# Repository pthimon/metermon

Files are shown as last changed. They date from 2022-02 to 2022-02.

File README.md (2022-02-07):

# Battery-Powered Utility Meter Usage Monitor

Do you have a "dumb" utility meter that you want to be able to track your usage
without replacing it? And do you want to run it from a battery? Then this
project is for you! (If you do have a power socket nearby then other projects e.g.
[Home Assistant Glow](https://github.com/klaasnicolaas/home-assistant-glow) are
more appropriate)

## Prerequisites

Your utility meter must either have an LED that pulses for each unit consumed,
or have a magnet in the dial that can be tracked with a reed switch.

IMAGE ELECTRICITY METER
IMAGE GAS METER

If your utility meter has 2 rates (e.g. Economy 7 electricity meter) then make
2 of the photodiode boards and use the `meter_2_rates` project, otherwise use
the `meter_1_rate` project.

You will also need an MQTT broker installed and (optionally) a Home Assistant
server.

## Hardware

- Low-power-capable ESP32 ([FireBeetle ESP32-E IoT Microcontroller](https://thepihut.com/products/firebeetle-esp32-e-iot-microcontroller-supports-wi-fi-bluetooth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))
- Dupont jumpers
- Photodiode or reed switch (depending on your meter type)
- 1 MOhm resistor (brown black green)
- [Vero/strip board](https://www.amazon.co.uk/gp/product/B08D2HP4B3/ref=ppx_yo_dt_b_asin_title_o06_s00?ie=UTF8&psc=1)
- [LiPo battery](https://www.amazon.co.uk/gp/product/B08214DJLJ/ref=ppx_yo_dt_b_asin_title_o00_s00?ie=UTF8&psc=1)
(1,000 - 2,000 mAh capacity should be plenty)
- USB C cable
- Blu Tack / electrical tape
- (Optional) Male header pins (if your ESP comes with soldered headers, you'll need 3 more pins)
- (Optional) USB power bank

## Tools

- Soldering iron
- Sharp knife (to cut low power trace)
- Side cutters (to trim resistor/photosensor leads)
- Tiny screwdriver (to fix battery connector)
- (Optional) 3D Printer
- (Optional) Breadboard (to help solder header pins)
- (Optional) Multi-meter (to assist positioning reed switch)

# Preparing Hardware

If your FireBeetle comes without headers pins, then solder them on. If you do not
have additional header pins, then break off a set of three pins before soldering,
making sure that the missing pins are furthest away from the USB port.

The easiest way to solder is to use a breadboard to hold the pins in place
while they are soldered.

Cut the "Low power" trace with a sharp knife. After doing this I measured the
deep sleep current to be about 14 uA.

[IMAGE TRACE]

## Sensors

The photodiode or reed switch can be connected to pin A3 (for the first sensor)
or pint A1 (if connecting a second sensor):

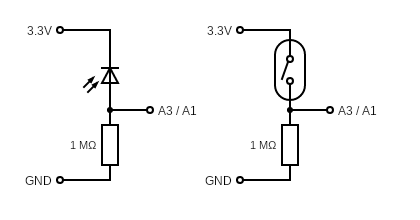
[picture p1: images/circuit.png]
Circuit


Cut the veroboard into a 3x3 square (11x11mm) with a sharp knife or old side cutters.

Solder the 3 header pins, the resistor and either the photodiode or the reed
switch to the board.

The photodiode should have its flat edge against the 3.3V pin.

Ensure the photodiode is on the opposite side of the board to the
header pins so that it can be positioned flush against the LED on the meter, or
that the reed switch has enough slack in the connecting wires to be easily
positioned in the correct place on the meter.

[IMAGE PHOTODIODE]

[IMAGE REEDSWITCH]

# Installing Software

Follow the [quickstart for ESP-IDF](https://docs.espressif.com/projects/esp-idf/en/latest/esp32/get-started/index.html)
to install the SDK and any dependencies.
Install [usb serial drivers](https://wiki.dfrobot.com/FireBeetle_Board_ESP32_E_SKU_DFR0654#target_11) (if necessary)

`. $HOME/esp/esp-idf/export.sh` (or where you installed the esp-idf SDK)

Clone this repository

`cd meter_1_rate` (if using one photodiode/reed switch)<br>
or<br>
`cd meter_2_rates` (if using 2 photodiodes)

`idf.py menuconfig`

Select "Meter Configuration":

- Enter the meter name, which is used as the MQTT topic prefix, e.g. `electricity` or `gas`
- WiFi network name (ssid)
- WiFi password
- MQTT broker URL
- Use Static IP: Un-checked
- Use Button debug: Checked

Connect the FireBeetle to the USB port of the computer.

```bash
idf.py build
idf.py -p /dev/cu.wchusbserial1410 flash # (replace the port with the correct one for your device)
idf.py monitor
```

## Set static IP

Press the button marked with `27` (*not* the `RST` button) on the FireBeetle. The
green LED will flash, and log entries will appear in the console. Find out the IP address
assigned by looking for the log line starting `got ip:`, and configure your
router so that the device is given a static IP address. This will save a lot of
battery life by speeding up the WiFi connect process.

`idf.py menuconfig`

Select "Meter Configuration":

- Use Static IP: Checked
- Static IP address
- Gateway IP (IP address of your router)
- Netmask

```bash
idf.py build
idf.py -p /dev/cu.wchusbserial1410 flash # (replace the port with the correct one for your device)
idf.py monitor
```

## Test

Using a program such as MQTT Explorer, you can verify that the pulse count is
being correctly published to `{meter_name}/total`, and the battery voltage to
`{meter_name}/battery`. (Ensure you are connected before pressing the button).

If the count isn't received by MQTT, the debug level can be increased to show more
information during the WiFi and MQTT connect process by changing the menuconfig:
"Component Config" > "Log Output" > "Default Log Verbosity": "Verbose"

## Install

Install the final version of the software.

`idf.py menuconfig`

Select "Meter Configuration":

- Use Button debug: Un-checked

```bash
idf.py build
idf.py -p /dev/cu.wchusbserial1410 flash # (replace the port with the correct one for your device)
```

## Battery

Before connecting the battery **double check the polarity of the connector**.
If the red wire does not line up with the `+` symbol on the board, then use a
tiny screwdriver to lift the tab to swap over the wires in the connector.

Connect the battery to the FireBeetle to charge it while connected via USB to
the computer. The red light will be solid while charging, and will flash
rapidly once charged. It should reach about 4.2V when fully charged. The
battery should have protection to not discharge below 2.5 V, but to play it
safe, this project is setup to report 0% battery and go into deep sleep when the
voltage is below 3 V.

[IMAGE battery]

## Home Assistant

Edit your Home Assistant `configuration.yaml` to setup MQTT sensors to receive the
meter values and battery voltage and percentage.

Replace ``"electricity"`` in the `state_topic` with the name you configured your
MQTT topic prefix to be.

If necessary, replace `0.001` in the line containing
`value_template: "{{ value | float * 0.001 }}"`
based on how many impulses make a unit, as stated on the meter (e.g.
`1 imp = 0.001kWh`).

```yaml
sensor:
  - platform: mqtt
    name: Electricity Meter
    unique_id: electricity_meter
    state_class: total_increasing
    device_class: energy
    state_topic: "electricity/total"
    unit_of_measurement: kWh
    value_template: "{{ value | float * 0.001 }}"
  - platform: mqtt
    name: Electricity Meter Battery Voltage
    unique_id: electricity_meter_battery_voltage
    device_class: voltage
    state_topic: "electricity/battery"
    unit_of_measurement: V
    value_template: "{{ value | float }}"
  - platform: mqtt
    name: Electricity Meter Battery
    unique_id: electricity_meter_battery
    device_class: battery
    unit_of_measurement: "%"
    state_topic: "electricity/battery"
    value_template: "{{ (([(value|float - 3), 1.2]|min / 1.2) * 100) | round(1) }}"
```

Restart Home Assistant for this to take effect.

# Case

3D Print the following files, depending on your setup:

- Case body
- Case insert (to separate the battery and the FireBeetle)
- Case lid for 1 sensor or Case lid for 2 sensors

and

- Photosensor body
- Photosensor lid

or

- Reedswitch body
- Reedswitch lid

# Connect sensor and install

Connect the photodiode or reed switch board to the FireBeetle, matching pins
3.3, GND and A3

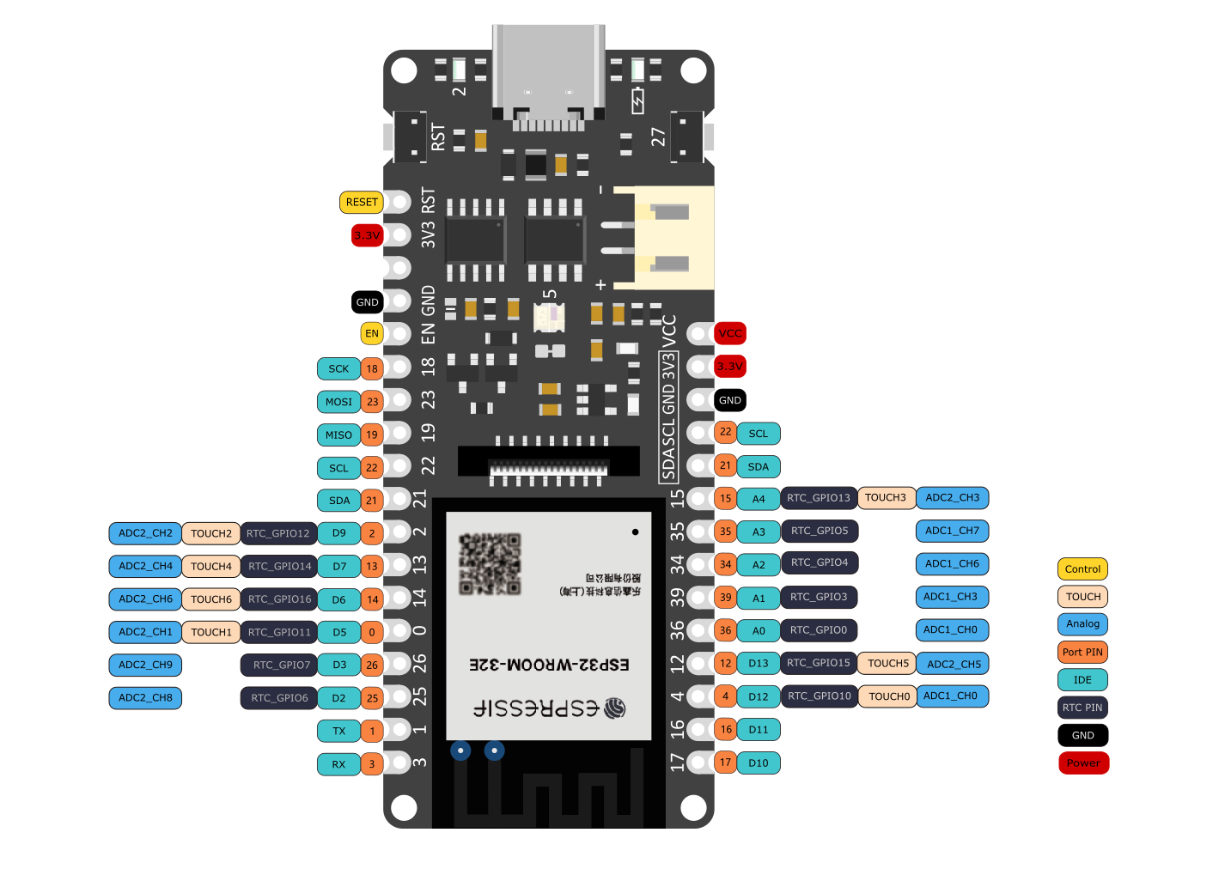
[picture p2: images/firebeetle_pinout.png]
Pinout


[IMAGE SENSOR PINOUT]

[IMAGE CONNECTED BOARD]

If you're using a second sensor board, connect to the other 3.3, GND and A1 pins.

Install on the meter so the photodiode covers the LED or the reed switch is in the
correct position to be triggered by the magnet in the dial.

It can help in positioning the reed switch to attach a multi-meter in continuity
mode across the reed switch while the meter is turning.

[IMAGE CONNECTED TO METER]

## Recharging

You can monitor the battery percentage in Home Assistant, and when it gets low,
connect a USB power bank to the USB port on the FireBeetle to recharge. As
mentioned above, it will go into deep sleep if the voltage goes below 3 V.

Do not leave the battery connected but discharged below 3 V for a long time
because it could damage the battery.

Current battery consumption is 3% in 10 days using a 1,100 mAh battery, so the
it should last around a year before needing to be recharged.

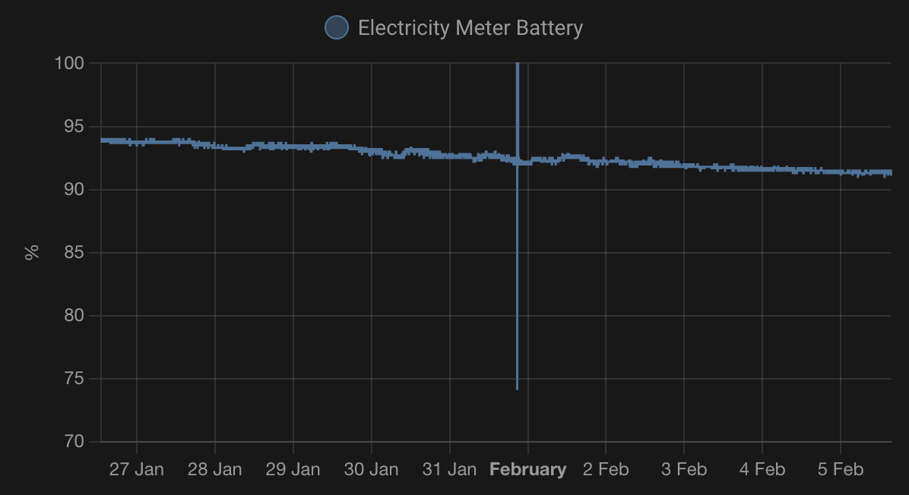
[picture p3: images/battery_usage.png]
Battery Usage


# Monitor

Use the energy dashboard in Home Assistant to track your usage.

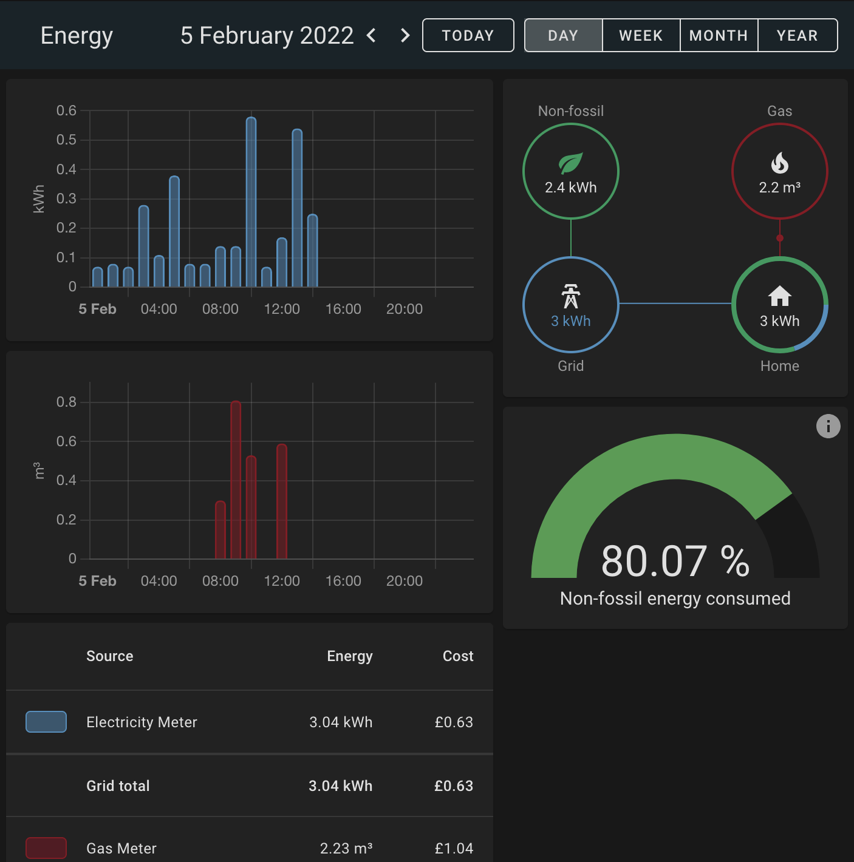
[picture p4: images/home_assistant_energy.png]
Energy Dashboard


To track the cost of gas, convert the price per kWh to the price per m³ using
the conversion formula given on your gas bill.

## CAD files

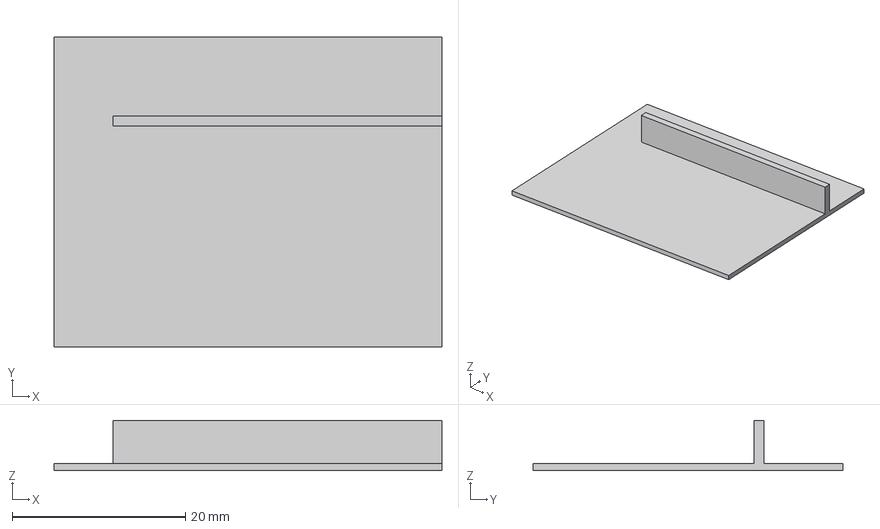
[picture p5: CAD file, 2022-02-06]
case/case_insert.3mf
44.8 x 35.8 x 5.80 mm

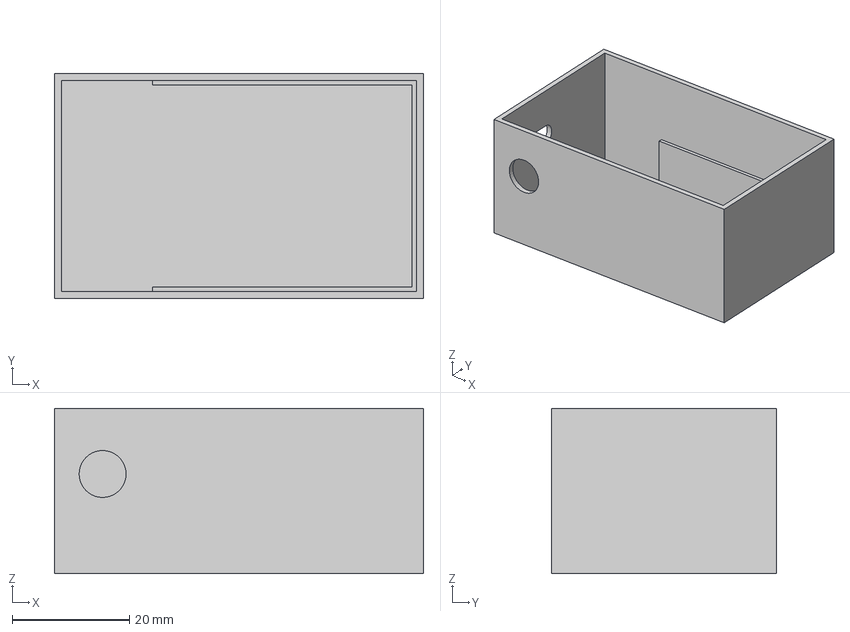
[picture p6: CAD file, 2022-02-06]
case/case.3mf
62.9 x 38.4 x 28.2 mm

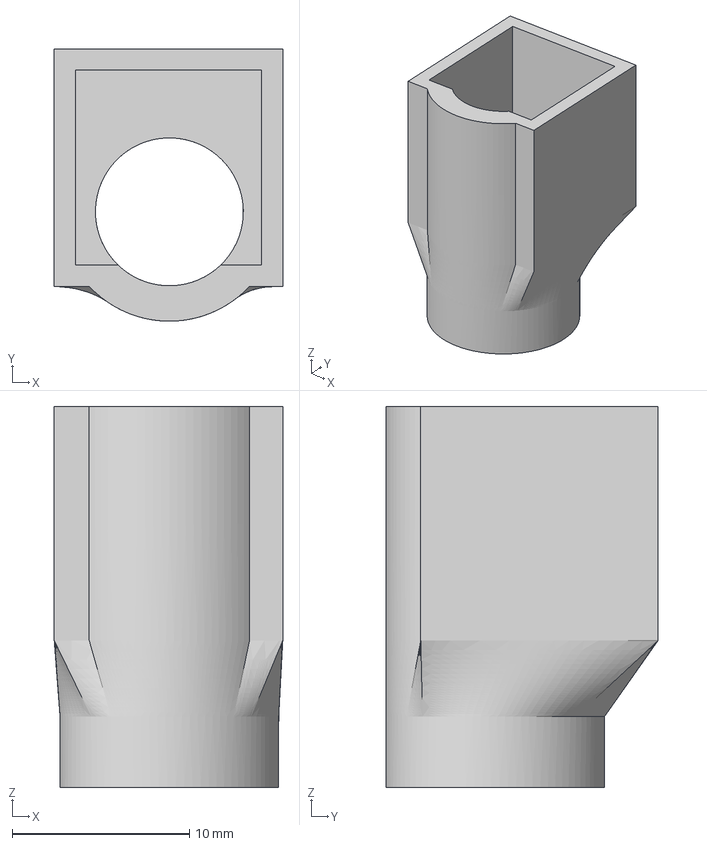
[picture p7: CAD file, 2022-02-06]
case/photosensor_body.3mf
12.9 x 15.4 x 21.5 mm

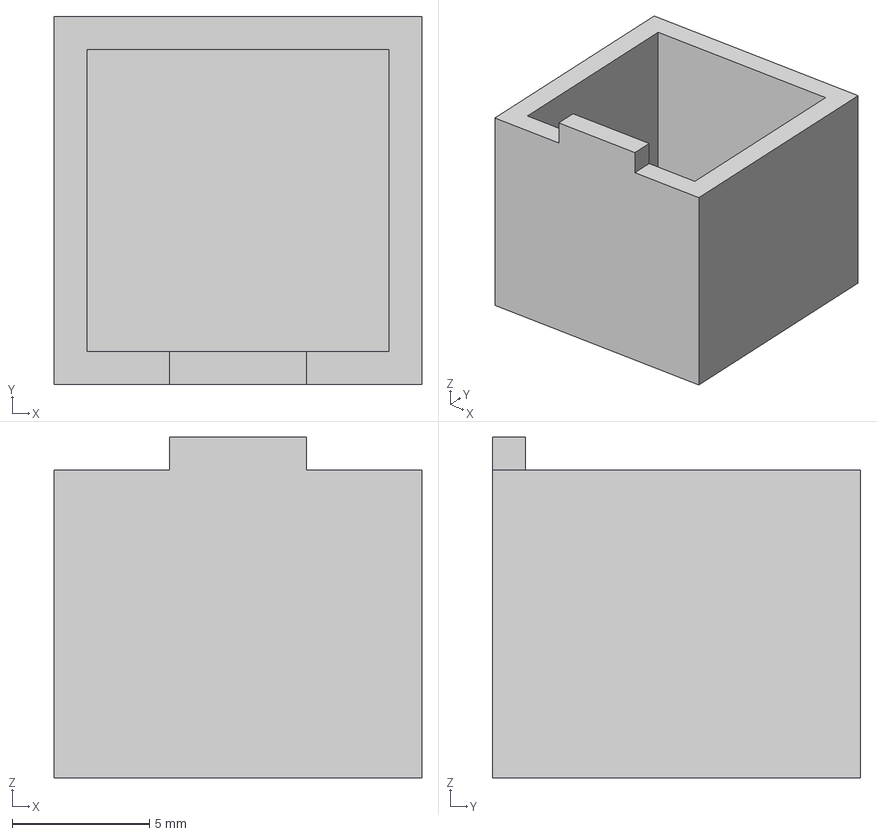
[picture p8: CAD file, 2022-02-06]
case/reedswitch_body.3mf
13.4 x 13.4 x 12.4 mm

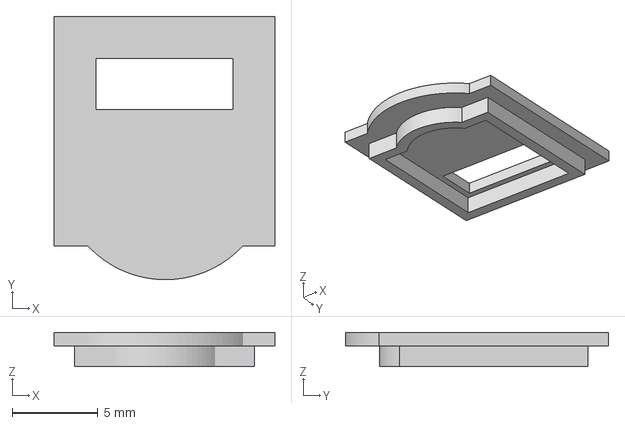
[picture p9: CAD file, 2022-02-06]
case/photosensor_lid.3mf
12.9 x 15.4 x 2.00 mm

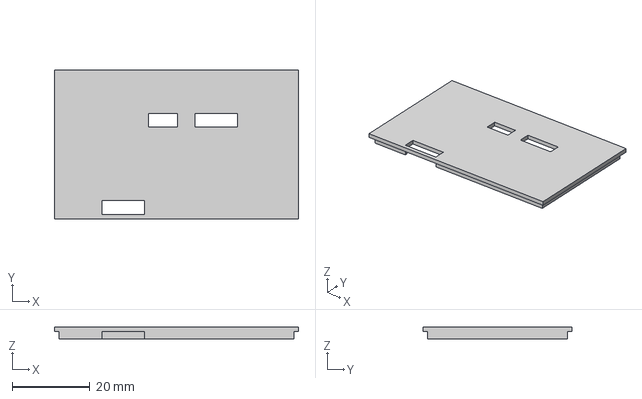
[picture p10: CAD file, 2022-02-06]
case/case_lid_2.3mf
62.9 x 38.4 x 3.20 mm

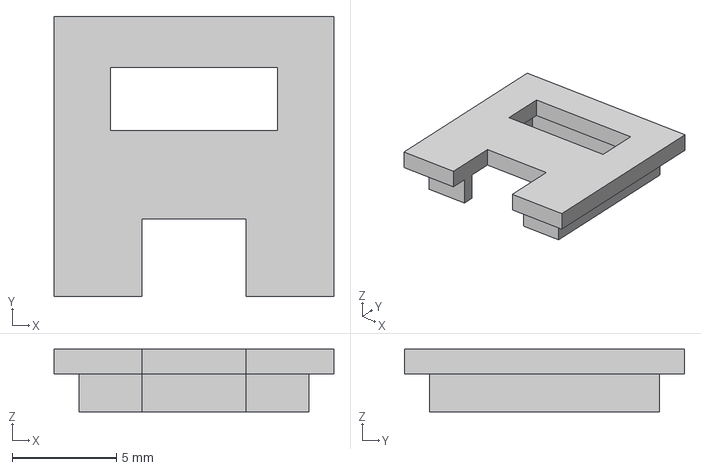
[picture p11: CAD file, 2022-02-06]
case/reedswitch_lid.3mf
13.4 x 13.4 x 3.00 mm

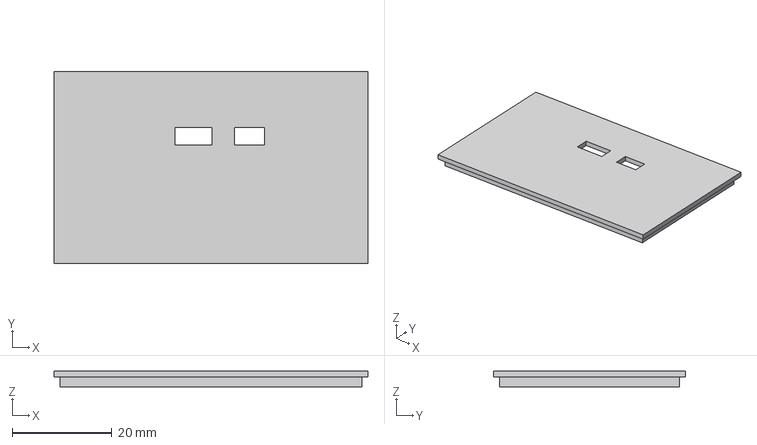
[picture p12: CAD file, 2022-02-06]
case/case_lid_1.3mf
62.9 x 38.4 x 3.20 mm

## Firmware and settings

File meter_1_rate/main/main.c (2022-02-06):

/*
   Unless required by applicable law or agreed to in writing, this
   software is distributed on an "AS IS" BASIS, WITHOUT WARRANTIES OR
   CONDITIONS OF ANY KIND, either express or implied.
*/

#include <stdio.h>
#include <string.h>
#include <stdint.h>
#include <stddef.h>

#include "ulp_main.h"
#include "esp32/ulp.h"
#include "driver/gpio.h"

#include "mqtt_client.h"

#include "battery.h"
#include "mqtt_connect.h"
#include "pulse_counter.h"
#include "wifi_client.h"

extern const uint8_t ulp_main_bin_start[] asm("_binary_ulp_main_bin_start");
extern const uint8_t ulp_main_bin_end[]   asm("_binary_ulp_main_bin_end");

static void init_ulp_program(void);

static float battery_voltage;

#if CONFIG_RESET_NVS
#define RESET_NVS true
#else
#define RESET_NVS false
#endif

#if CONFIG_USE_BUTTON_DEBUG
#define USE_BUTTON_DEBUG true
#else
#define USE_BUTTON_DEBUG false
#endif


void on_mqtt_connect(esp_mqtt_client_handle_t mqtt_client) {
  uint32_t pulse_count = 0;
  uint32_t pulse_count_total = 0;
  update_pulse_count("rate_1", &ulp_edge_count, &pulse_count, &pulse_count_total);

  char pulse_count_str[50];
  sprintf(pulse_count_str, "%u", pulse_count);
  char total_topic_str[50];
  sprintf(total_topic_str, "%s/total", CONFIG_METER_NAME);
  esp_mqtt_client_publish(mqtt_client, total_topic_str, pulse_count_str, 0, 1, 0);
  printf("Publishing %s to %s/total\n", pulse_count_str, CONFIG_METER_NAME);

  char battery_str[50];
  sprintf(battery_str, "%4.3f", battery_voltage);
  char battery_topic_str[50];
  sprintf(battery_topic_str, "%s/battery", CONFIG_METER_NAME);
  esp_mqtt_client_publish(mqtt_client, battery_topic_str, battery_str, 0, 1, 0);
}

void on_wifi_connect(void) {
    mqtt_publish(on_mqtt_connect);
}

void app_main(void) {
    // read the battery volatage and go into deep sleep if below critical voltage
    battery_voltage = check_battery();
    if (RESET_NVS) {
        // recompile to reset the stored counter if necessary
        reset_nvs(CONFIG_RESET_NVS_VALUE);
        printf("Reset NVS values to %d", CONFIG_RESET_NVS_VALUE);
    } else {
        pulse_count_main(init_ulp_program, on_wifi_connect);
    }
}

static void init_ulp_program(void) {
    esp_err_t err = ulp_load_binary(0, ulp_main_bin_start,
            (ulp_main_bin_end - ulp_main_bin_start) / sizeof(uint32_t));
    ESP_ERROR_CHECK(err);

    /* GPIO used for pulse counting. */
    gpio_num_t gpio_num;
    if (USE_BUTTON_DEBUG) {
        gpio_num = GPIO_NUM_27;  // button
    } else {
        gpio_num = GPIO_NUM_35;  // A3
    }

    int rtcio_num = init_pin(gpio_num);

    /* Initialize some variables used by ULP program.
     * Each 'ulp_xyz' variable corresponds to 'xyz' variable in the ULP program.
     * These variables are declared in an auto generated header file,
     * 'ulp_main.h', name of this file is defined in component.mk as ULP_APP_NAME.
     * These variables are located in RTC_SLOW_MEM and can be accessed both by the
     * ULP and the main CPUs.
     *
     * Note that the ULP reads only the lower 16 bits of these variables.
     */
    ulp_debounce_counter = 3;
    ulp_debounce_max_count = 3;
    ulp_next_edge = 0;
    ulp_io_number = rtcio_num; /* map from GPIO# to RTC_IO# */
    if (USE_BUTTON_DEBUG) {
        // wake up after each button press (2 edge counts)
        ulp_edge_count_to_wake_up = 2;
    } else {
        // wake up after 10 pulses (e.g. 0.01 kWh or 0.01 m3)
        ulp_edge_count_to_wake_up = CONFIG_PULSE_COUNT_BEFORE_WAKEUP * 2;
    }

    /* Set ULP wake up period to T = 20ms.
     * Minimum pulse width has to be T * (ulp_debounce_counter + 1) = 80ms.
     */
    ulp_set_wakeup_period(0, 20000);

    /* Start the program */
    err = ulp_run(&ulp_entry - RTC_SLOW_MEM);
    ESP_ERROR_CHECK(err);
}

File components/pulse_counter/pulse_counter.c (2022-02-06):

#include <stdio.h>

#include "nvs.h"
#include "nvs_flash.h"
#include "soc/rtc_cntl_reg.h"
#include "soc/sens_reg.h"
#include "soc/rtc_periph.h"
#include "driver/gpio.h"
#include "driver/rtc_io.h"

#include "freertos/FreeRTOS.h"
#include "freertos/semphr.h"

#include "esp_sleep.h"
#include "esp_netif.h"
#include "esp_wifi.h"

#include "pulse_counter.h"
#include "wifi_client.h"

int init_pin(int gpio_num)
{
    int rtcio_num = rtc_io_number_get(gpio_num);
    assert(rtc_gpio_is_valid_gpio(gpio_num) && "GPIO used for pulse counting must be an RTC IO");

    /* Initialize selected GPIO as RTC IO, enable input, disable pullup and pulldown */
    rtc_gpio_init(gpio_num);
    rtc_gpio_set_direction(gpio_num, RTC_GPIO_MODE_INPUT_ONLY);
    rtc_gpio_pulldown_dis(gpio_num);
    // rtc_gpio_pullup_en(gpio_num);
    if (gpio_num == GPIO_NUM_27) {
      rtc_gpio_pullup_en(gpio_num);
    } else {
      rtc_gpio_pullup_dis(gpio_num);
    }
    rtc_gpio_hold_en(gpio_num);

    return rtcio_num;
}

void reset_nvs(uint32_t rate_1) {
    reset_nvs_2(rate_1, 0);
}

// only call to initialise NVS to meter reading or zero
void reset_nvs_2(uint32_t rate_1, uint32_t rate_2) {
  const char* namespace = "plusecnt";

  nvs_handle_t handle;
  nvs_flash_init();
  ESP_ERROR_CHECK(nvs_open(namespace, NVS_READWRITE, &handle));
  ESP_ERROR_CHECK(nvs_set_u32(handle, "rate_1", rate_1));
  ESP_ERROR_CHECK(nvs_set_u32(handle, "rate_2", rate_2));
  ESP_ERROR_CHECK(nvs_set_u32(handle, "count", rate_1 + rate_2));
  ESP_ERROR_CHECK(nvs_commit(handle));
  nvs_close(handle);
}


void update_pulse_count(char* topic, uint32_t* edge_count,
        uint32_t* pulse_count, uint32_t* pulse_count_total)
{
    const char* namespace = "plusecnt";
    const char* total_key = "count";

    nvs_handle_t handle;
    ESP_ERROR_CHECK( nvs_open(namespace, NVS_READWRITE, &handle));
    esp_err_t err = nvs_get_u32(handle, topic, pulse_count);
    assert(err == ESP_OK || err == ESP_ERR_NVS_NOT_FOUND);
    err = nvs_get_u32(handle, total_key, pulse_count_total);
    assert(err == ESP_OK || err == ESP_ERR_NVS_NOT_FOUND);
    printf("Read pulse count from NVS: %5d, %5d\n", *pulse_count, *pulse_count_total);

    /* ULP program counts signal edges, convert that to the number of pulses */
    uint32_t pulse_count_from_ulp = (*edge_count & UINT16_MAX) / 2;
    /* In case of an odd number of edges, keep one until next time */
    *edge_count = *edge_count % 2;
    printf("Pulse count from ULP: %5d\n", pulse_count_from_ulp);

    /* Save the new pulse count to NVS */
    *pulse_count = *pulse_count + pulse_count_from_ulp;
    ESP_ERROR_CHECK(nvs_set_u32(handle, topic, *pulse_count));
    *pulse_count_total = *pulse_count_total + pulse_count_from_ulp;
    ESP_ERROR_CHECK(nvs_set_u32(handle, total_key, *pulse_count_total));
    ESP_ERROR_CHECK(nvs_commit(handle));
    nvs_close(handle);
    printf("Wrote updated pulse count to NVS: %5d, %5d\n", *pulse_count, *pulse_count_total);
}

void pulse_count_main(void init_ulp_program(void), void on_wifi_connect(void)) {
  // flash LED
  gpio_set_direction(GPIO_NUM_2, GPIO_MODE_OUTPUT);
  gpio_set_level(GPIO_NUM_2, 1);

  esp_sleep_wakeup_cause_t cause = esp_sleep_get_wakeup_cause();
  if (cause != ESP_SLEEP_WAKEUP_ULP) {
      printf("Not ULP wakeup, initializing ULP\n");
      init_ulp_program();

      /* Disconnect GPIO12 and GPIO15 to remove current drain through
       * pullup/pulldown resistors.
       * GPIO12 may be pulled high to select flash voltage.
       */
      rtc_gpio_isolate(GPIO_NUM_12);
      rtc_gpio_isolate(GPIO_NUM_15);
      esp_deep_sleep_disable_rom_logging(); // suppress boot messages
      vTaskDelay(pdMS_TO_TICKS(500));
  } else {
      printf("ULP wakeup, saving pulse count\n");

      //Initialize NVS
      esp_err_t ret = nvs_flash_init();
      if (ret == ESP_ERR_NVS_NO_FREE_PAGES || ret == ESP_ERR_NVS_NEW_VERSION_FOUND) {
        ESP_ERROR_CHECK(nvs_flash_erase());
        ret = nvs_flash_init();
      }
      ESP_ERROR_CHECK(ret);

      // connect to wifi
      ESP_ERROR_CHECK(esp_netif_init());
      wifi_init_sta(on_wifi_connect);
  }

  // unflash LED
  gpio_set_level(GPIO_NUM_2, 0);

  printf("Entering deep sleep\n\n");
  ESP_ERROR_CHECK( esp_sleep_enable_ulp_wakeup() );
  esp_deep_sleep_start();
}

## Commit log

2022-02-06 Add circuit diagram
2022-02-06 Add space for connectors
    [case.3mf, case_insert.3mf]
2022-02-07 Update gas device_class
